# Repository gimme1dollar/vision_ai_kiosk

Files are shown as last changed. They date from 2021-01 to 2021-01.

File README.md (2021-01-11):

# Viosk
폭 넓은 사용층을 고려한 AI-기반의 **비전인식 키오스크** 
- [소개 영상](https://drive.google.com/file/d/1KaQiv4moTRgdAZZi3DC1T_f7XEgCQWQI/view?usp=sharing) 
    - 이미지 출처: `files/_image_reference.txt`
- [시연 영상](https://drive.google.com/file/d/1vzOOIthxaEInF-no1CoXh7OKscDMb2IW/view?usp=sharing)
- [발표 자료](https://drive.google.com/file/d/1hJ28Oalcn_aavSERfy1kXunzW1Yjd5MP/view?usp=sharing)

### 🎉 수상 🎉
[2021 서울 하드웨어 해커톤](https://www.seoulhackathon.org/692) 에서 우수상을 수상했습니다.

## 개요
### Goal
1. 코로나-19 시대 이후 비접촉 무인 시스템의 활성화로 인해 더 많아진 터치스크린 기반 키오스크의
2. 사용을 어려워하는 글자를 읽는 데에 어려움이 있으시는 분, 높이가 맞지 않아 터치가 힘드신 분, 휠체어를 타시는 분들을 위해
3. 비전 인식 AI를 활용해 더 나은 사용 환경을 제공하는 키오스크

### Overall Structure
<p align="center">
	
	
	
</p>

## Development
### Environment
#### STM32
- STM-B-L4S5I-IOT01A : Board
- STM32CubeMX : Development Tool
- STM32CubeAI : AI Library

#### Hardware 
- Fusion360 : 3D modeling
- Galaxy Tab : mini-screen Kiosk

#### Firmware
- Rasberry Pi : 사진 촬영 및 사진 전송 (UART)

#### Software
- Keras (ver.2.4.0) : Convolutional Neural Network for Vision Recognition
- Kotlin : Android Application Development

### Features
#### Age Detection
- [AgeGenderDeepLearning](https://github.com/GilLevi/AgeGenderDeepLearning) 모델을 base로 진행
- [IMDB-Wiki](https://data.vision.ee.ethz.ch/cvl/rrothe/imdb-wiki/) 로 학습

##### Normalize, class grouping, gray scale 변환 등의 preprocessing 진행
<p align="center">


</p>

##### Training 결과, 90%의 정확도를 보임
<p align="center">

</p>

##### Parameter 축소, quantization 등을 통해 여전히 높은 정확도를 보이는 lightweight 모델 생성 및 STM32 보드에 탑재
<p align="center">


</p>

#### UI
##### 초음파 센서를 이용해 키를 인지하고, 그에 맞춰 키오스크 높이를 조정
<p align="center">



</p>

##### Age detection 결과에 맞춰, UI를 변경
<p align="center">
    
</p>

## Contributors
<p align="center">
    
</p>

- 김현성(HW) - https://github.com/hyunsungkim
- 김주환(HW) - https://github.com/robotjuhwan  
- 이주용(SW) - https://github.com/gimme1dollar  
- 조승혁(SW) - https://github.com/seunghyukcho

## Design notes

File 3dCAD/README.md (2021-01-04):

# 3dCAD
- 3d CAD files (.stl)
- Fusion 360 (.f3d)
- Printable files of Cubicon machines (.hfb, .hvs)

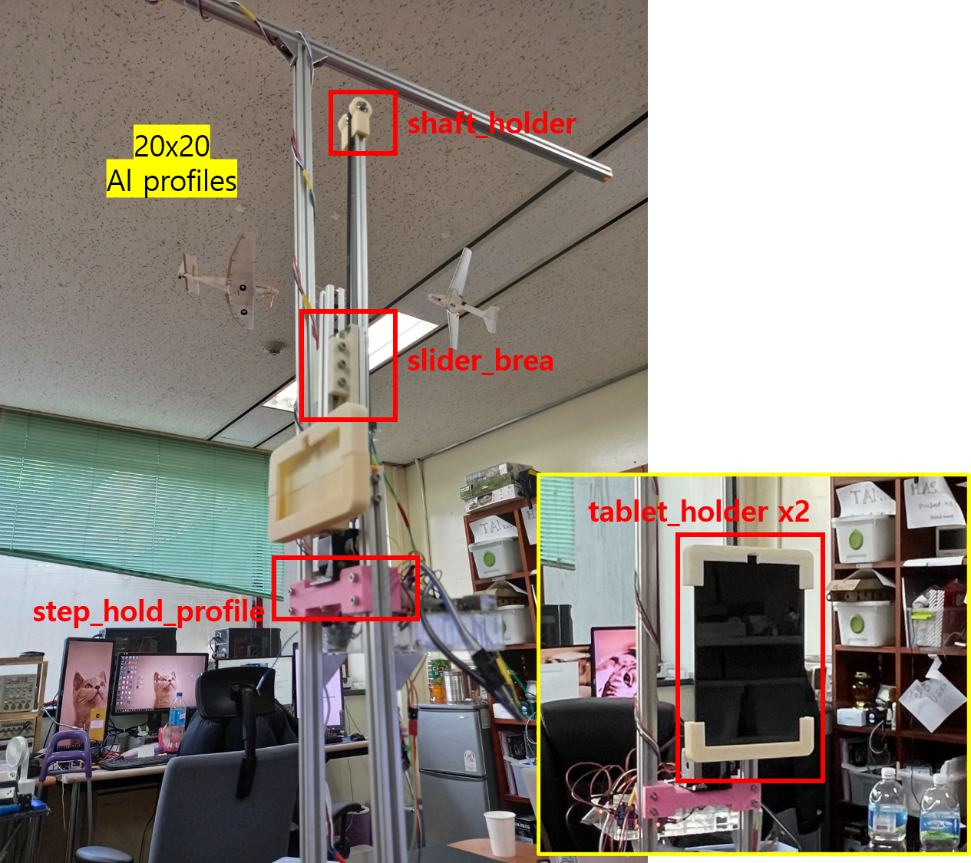
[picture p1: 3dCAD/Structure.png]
Structure


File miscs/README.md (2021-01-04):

# Miscellaneous sources

## Raspberry Pi
### Settings
1. ```sudo raspi-config```
2. Interface Options
3. Serial
4. Would you like a login shell to be accessible over serial? -> No
5. Would you like the serial port hardware to be enabled? -> Yes

### Connection to the STM board
Refer to firmware [README.md](../firmware/README.md)

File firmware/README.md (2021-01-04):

# STM32 Firmware
ST B-L4S5I-IOT01A 보드 펌웨어. 

## Environments

- ST B-L4S5I-IOT01A
- STM32CubeIDE v1.5.0
- [STM32Cube.AI][x-cube-ai-ref] v5.2.0
사용된 Tensorflow Lite model은 ai 디렉토리에 있으며, tensorflow 2.4.0 버젼에서 생성됨.

## Requirements

### Setting the STM board
Raspberry pi로부터 2Mbps의 속도로 UART 통신을 통해 이미지 데이터를 받아옴. 안정적인 통신을 위해 RTS/CTS를 통한 하드웨어 흐름제어가 필수적. RTS/CTS 흐름제어가 가능한 UART2 사용을 위해 B-L4S5I-IOT01A 보드 뒷면의 점퍼 전극을 다음과 같이 연결해야함.

SB12,16,19,20 - Close (납땜으로 연결)  
SB14,15,18,21 - Open (기존의 연결 제거)

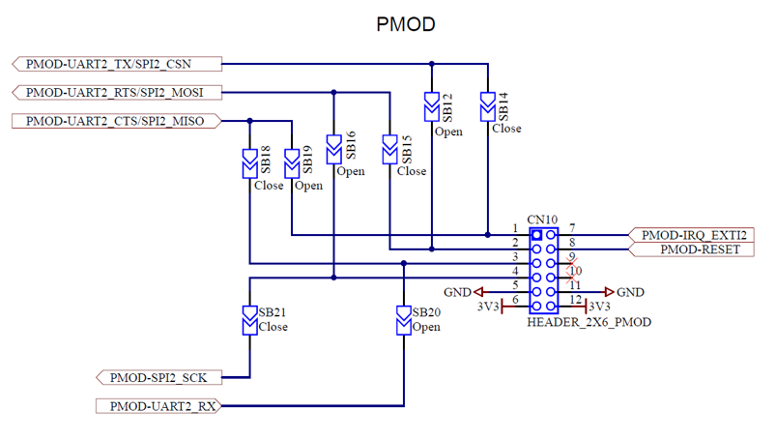
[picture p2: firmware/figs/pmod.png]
pmod


### Connections to peripherals
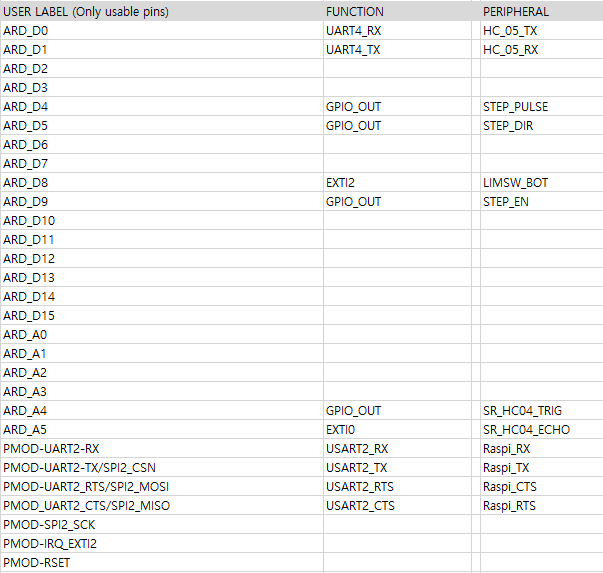
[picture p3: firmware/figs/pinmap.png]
pinmap


***SR-HC04***  
SR_HC04_TRIG : Trigger pin  
SR_HC04_ECHO : Echo pin

***MW-VSTB24D1S-v2***  
STEP_PULSE : CLK+  
STEP_DIR : DIR+  
STEP_EN : ENA+  

***HC-05***  
HC_05_TX : TX  
HC_05_RX : RX  
baud 9600bps

***Raspberry Pi 4***  
[Reference][rpi-rts-cts] 
Raspi_RX : pin 10  
Raspi_TX : pin 8  
Raspi_CTS : pin 36  
Raspi-RTS : pin 11  

## How to start

1) Raspberry Pi에서 serial.py 실행
2) STM32펌웨어 업로드 및 실행
3) 라즈베리파이 카메라에 얼굴을 비치고 SR-HC04로 사람이 감지되면 얼굴 촬영 후 나이 인식 및 키오스크 높이 조절

   [x-cube-ai-ref]: <https://www.st.com/resource/en/user_manual/dm00570145-getting-started-with-xcubeai-expansion-package-for-artificial-intelligence-ai-stmicroelectronics.pdf>
   [rpi-rts-cts]: <https://ethertubes.com/wp-content/uploads/uart_raspberry_pi_3_pinout.png>

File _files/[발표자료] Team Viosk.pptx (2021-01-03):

## Team Viosk

모두를 위한 비전인식 키오스크

## 문제점

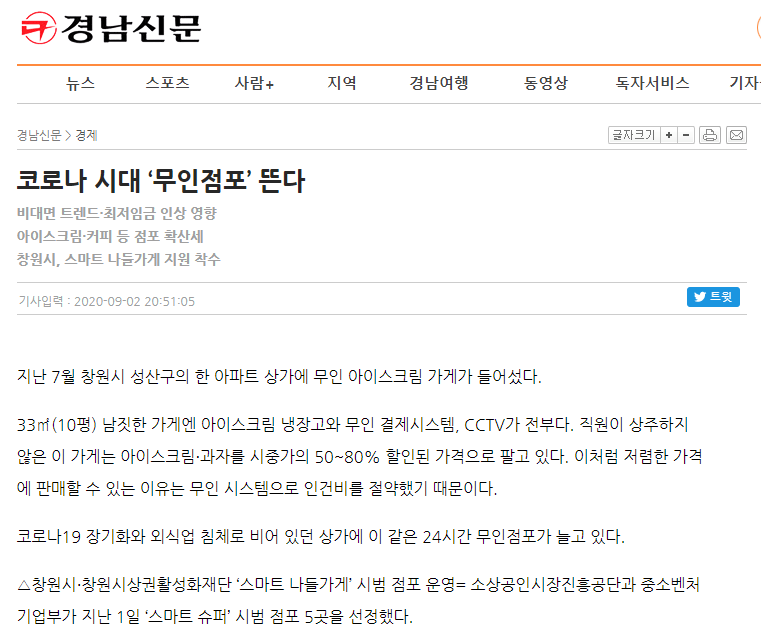
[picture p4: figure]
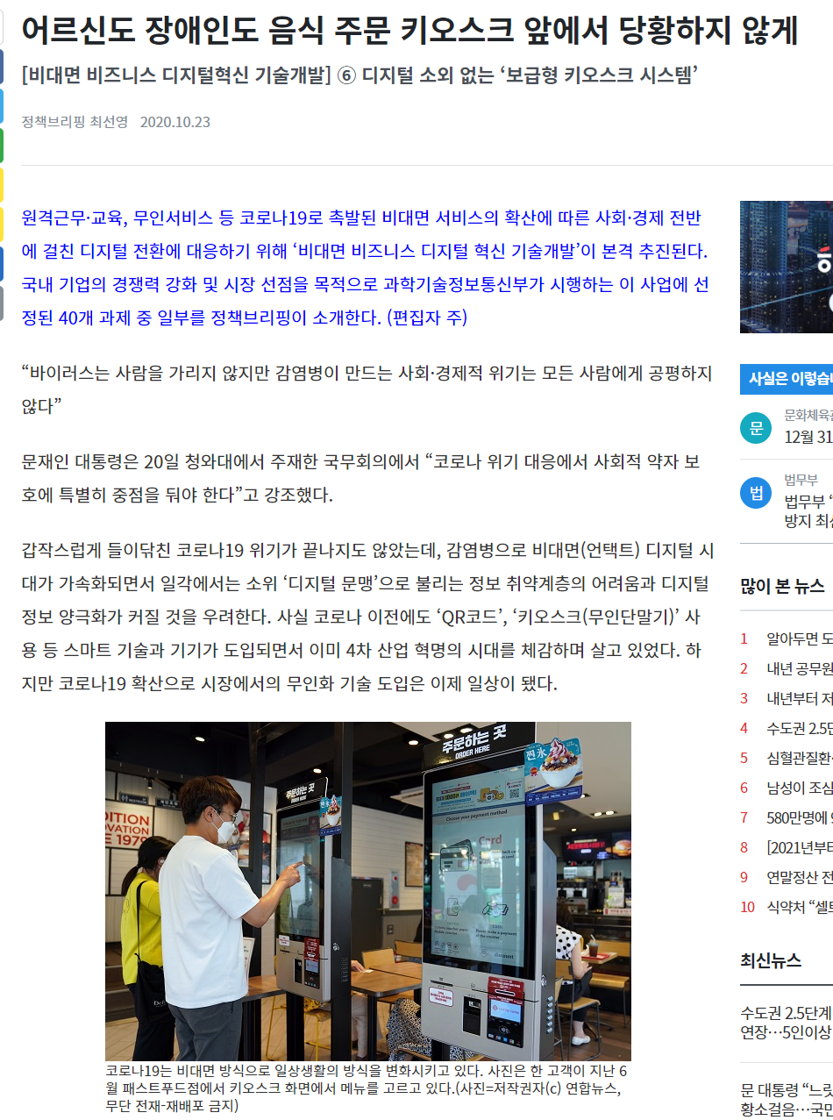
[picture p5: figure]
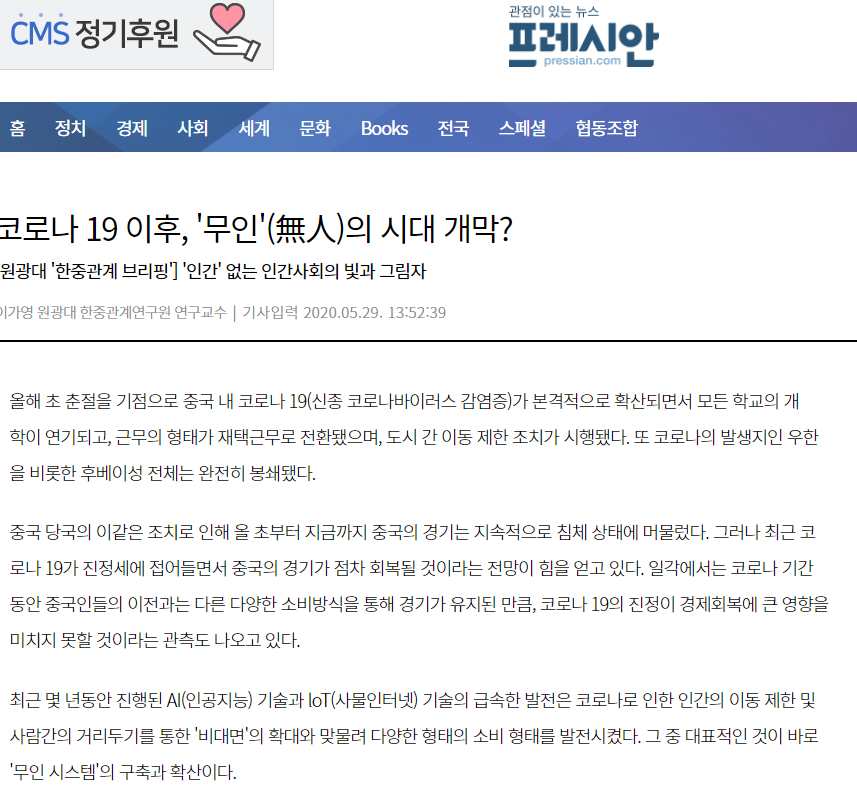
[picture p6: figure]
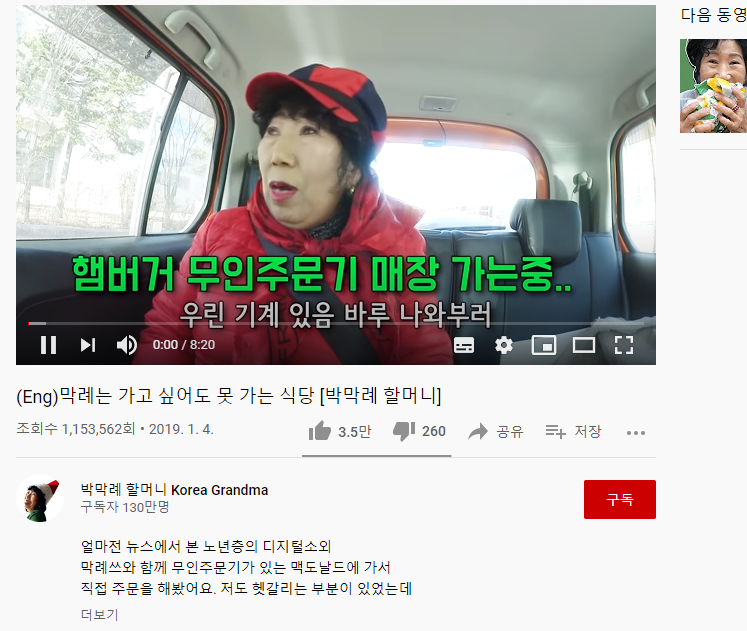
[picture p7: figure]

출처 : https://www.korea.kr/news/policyNewsView.do?newsId=148879041
https://www.pressian.com/pages/articles/2020052815135938466
http://www.knnews.co.kr/news/articleView.php?idxno=1333128
https://www.youtube.com/watch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

## 목표

- 코로나-19 시대 이후 비접촉 무인 시스템의 활성화로 인해 더 많아진 터치스크린 기반 키오스크의
- 글자를 읽는 데에 어려움이 있으시는 분, 높이가 맞지 않아 터치가 힘드신 분, 휠체어를 타시는 분들 등 사회 구성원 모두를 위해
- 비전 인식 AI를 활용해 더 나은 사용 환경을 제공하는 키오스크

## 해결책 - 자동화

- goal) AI를 이용해 사용자의 (1) 활동 DB와 (2) 의도를 읽어내어 주문 업무 완전 자동화
- 중간단계) 비전인식 및 음성인식을 활용해 사용자의 많은 정보를 추출하여 주문 업무 부분 자동화
- 현재 prototype) 비전 인식으로 사용자의 얼굴에서부터 정보 (나이 정보 등) 를 추출하고, 센서로 사용자 위치 추정을 활용해 더 나은 하드웨어/소프트웨어적인 UI 제공 자동화
- 해커톤 중점사항) 20만원 이하 수준의 리소스로 경량 AI 활용하여 10초 내외 정보 추출 및 UI 다양화 구상과 가능성 파악

## 구성

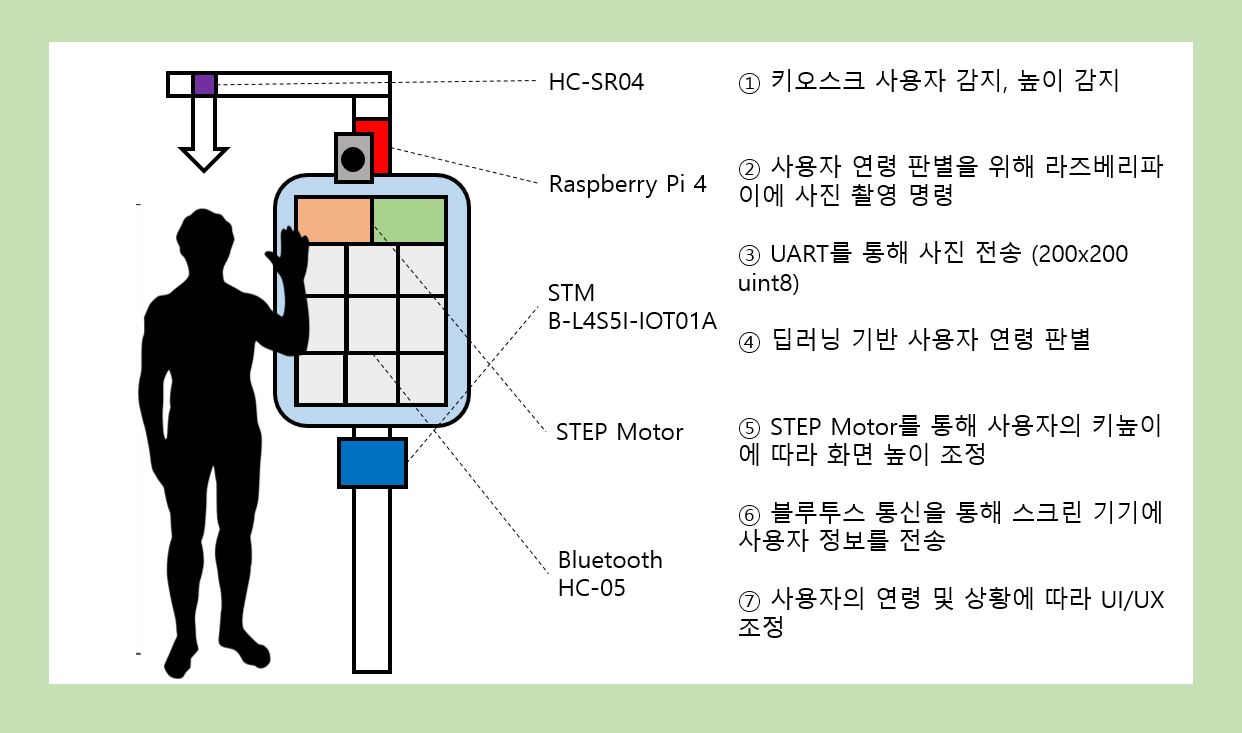
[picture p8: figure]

## 시스템

Bluetooth
HC-05

STM
B-L4S5I-IOT01A

DNN

HC-SR04

Touch Screen
UI/UX

⑥

⑥

STEP Motor

⑤

③

Raspberry Pi 4

④

②

①

⑦

## 개발 환경

STM32
- STM-B-L4S5I-IOT01A
- STM32Cube-MX : STM32 Development Tool
- STM32Cube-AI : STM32 AI 개발
Hardware
- Fusion360 : 3D modeling
- Galaxy Tab : mini-screen Kiosk
Firmware
- Rasberry Pi : 사진 촬영 및 사진 전송 (UART)
Software
- Keras (ver.2.4.0) : Convolutional Neural Network for Vision Recognition
- Kotlin : Android Application Development

## Development – 3D Modeling & 프레임

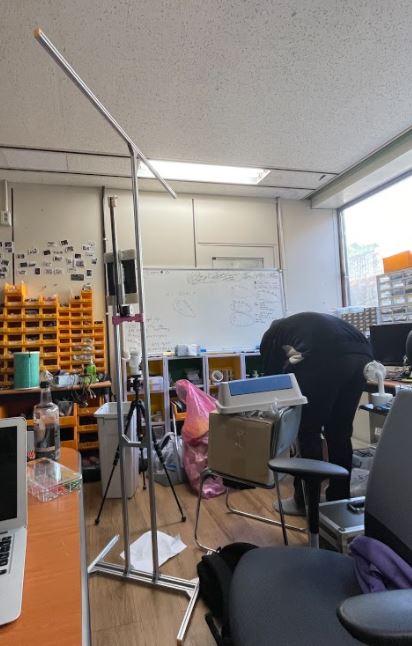
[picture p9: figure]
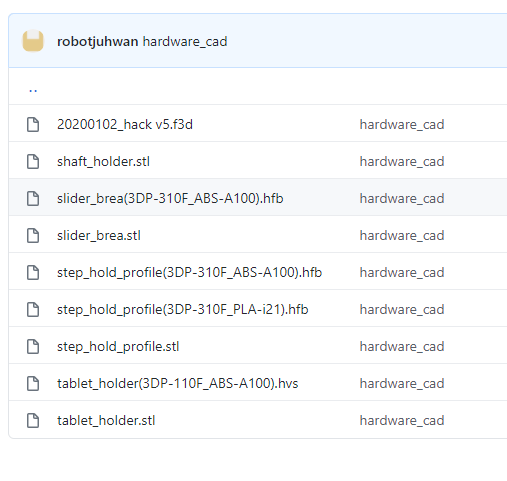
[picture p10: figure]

## Development – Image Preprocessing

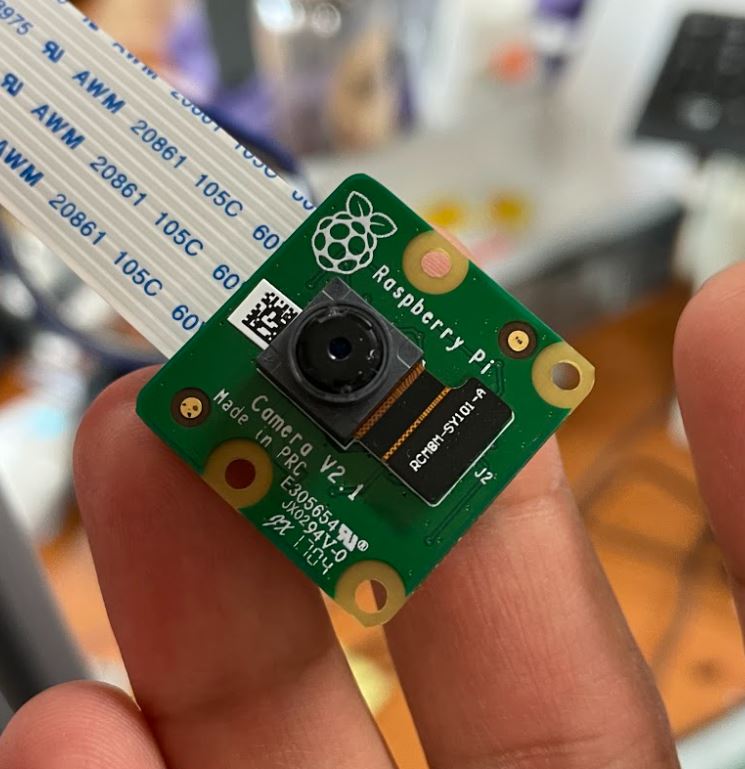
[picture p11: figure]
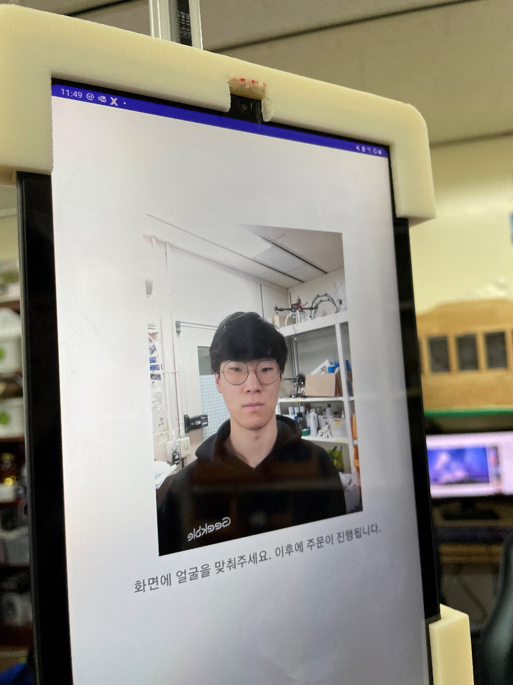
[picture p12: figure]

## Development – AI Training

- https://data.vision.ee.ethz.ch/cvl/rrothe/imdb-wiki/
- https://github.com/GilLevi/AgeGenderDeepLearning

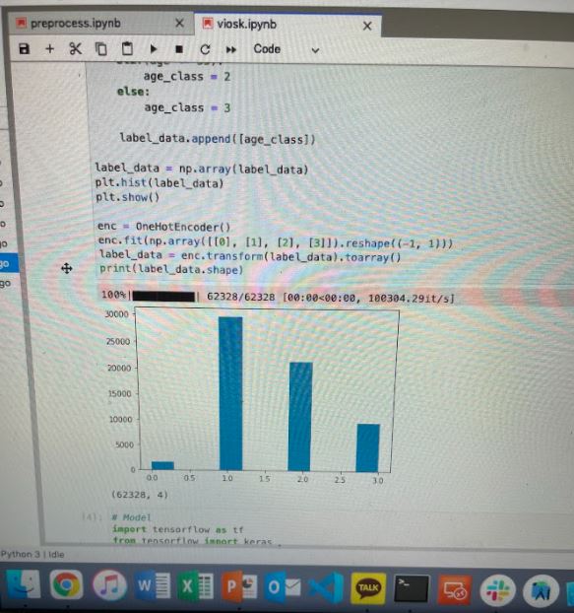
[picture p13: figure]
프리프로세싱
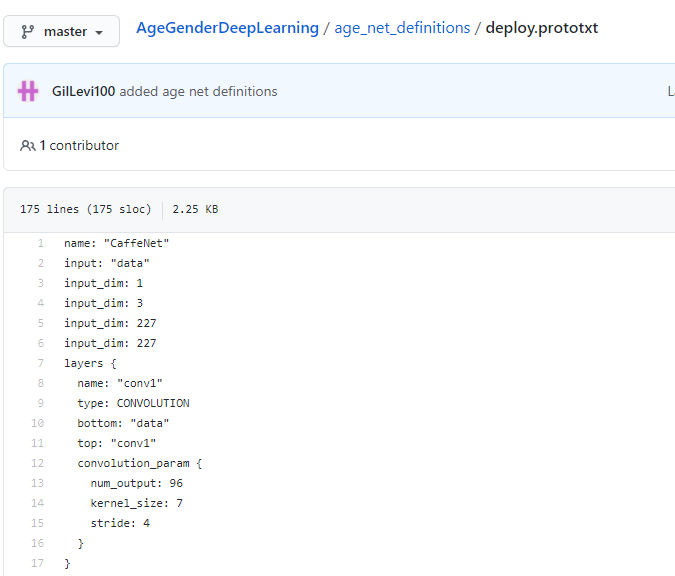
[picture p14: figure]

## Development – AI Model Quantization

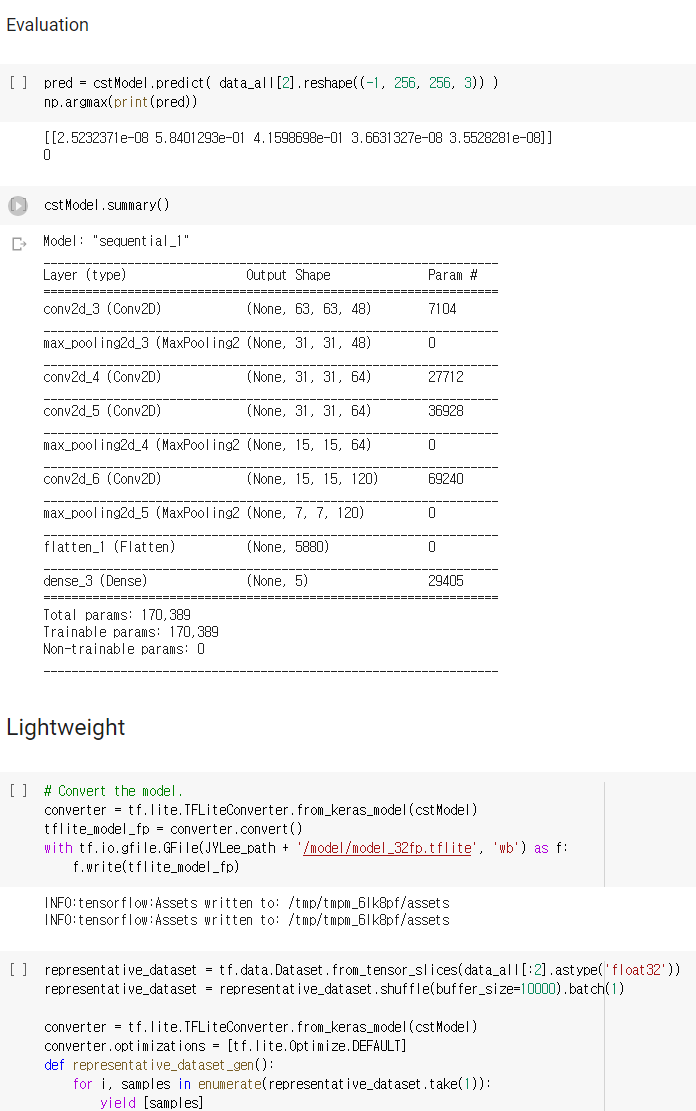
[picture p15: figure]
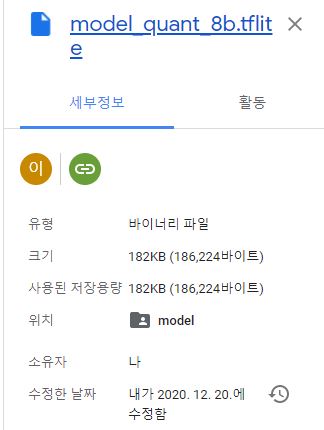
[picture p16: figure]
경량화

## Test – Age Detection

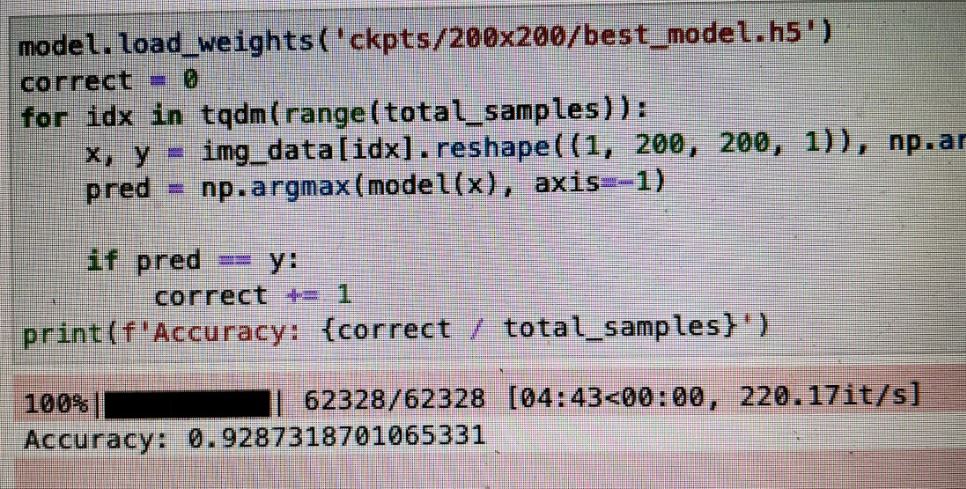
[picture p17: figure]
정확도
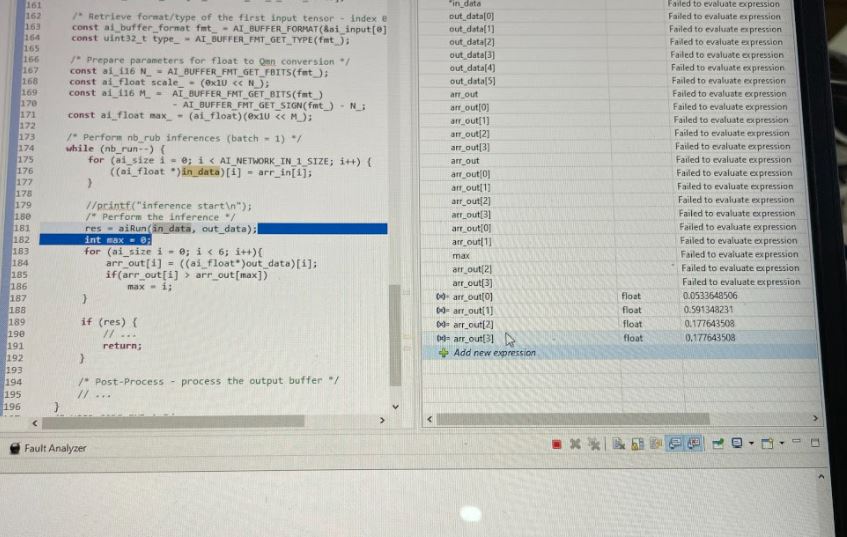
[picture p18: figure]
테스트on보드

## Test – Height Estimation

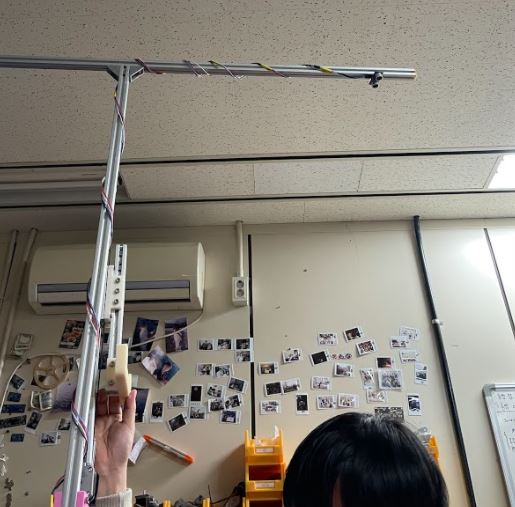
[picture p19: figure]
초음파
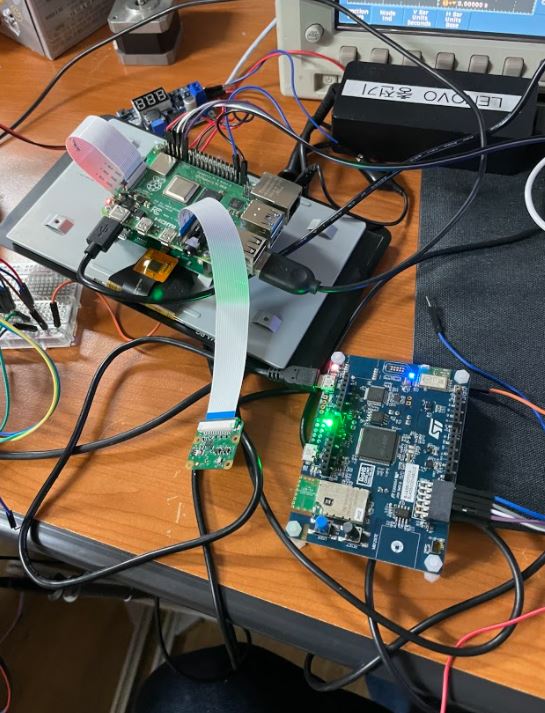
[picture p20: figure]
보드
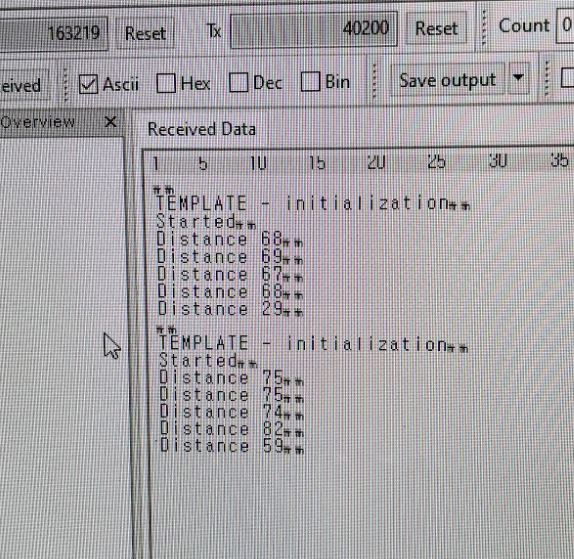
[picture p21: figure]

## Test – Hardware Adjustment

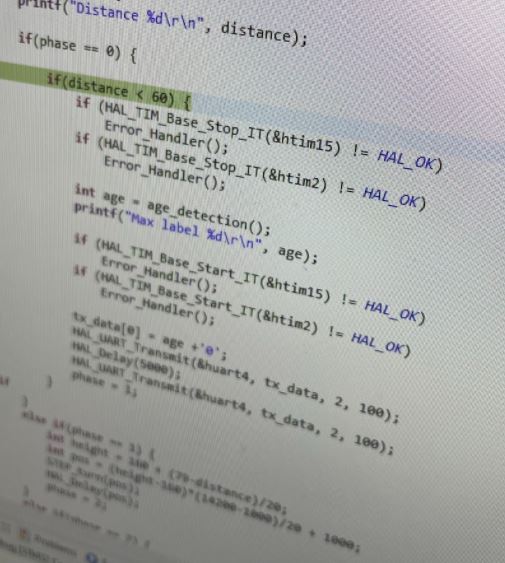
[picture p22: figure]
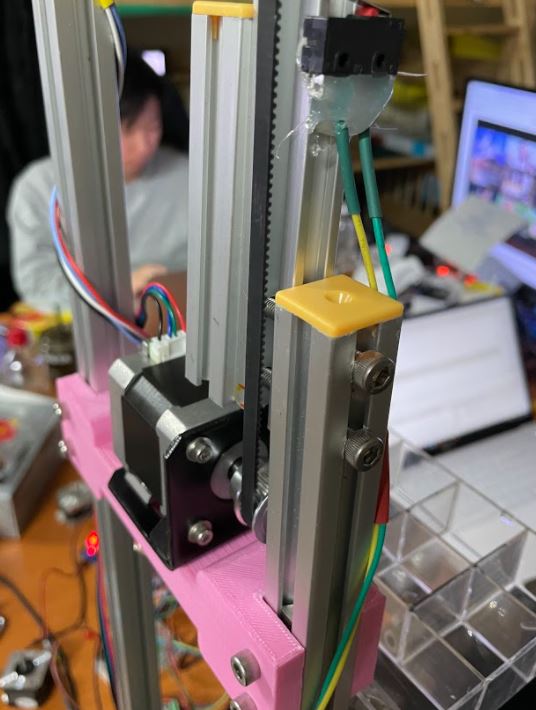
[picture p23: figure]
모터

## Test – UI Variation

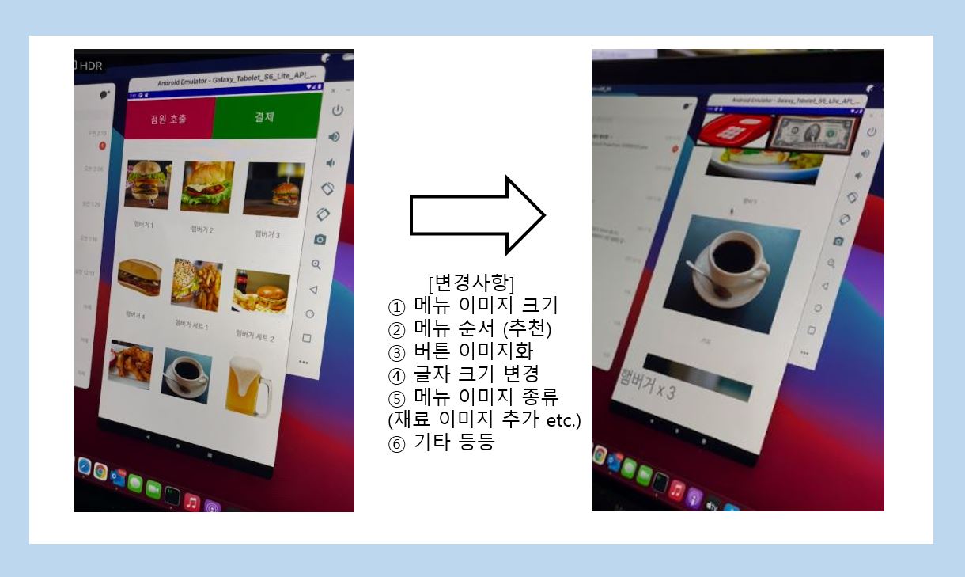
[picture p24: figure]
UI버전

## 감사합니다

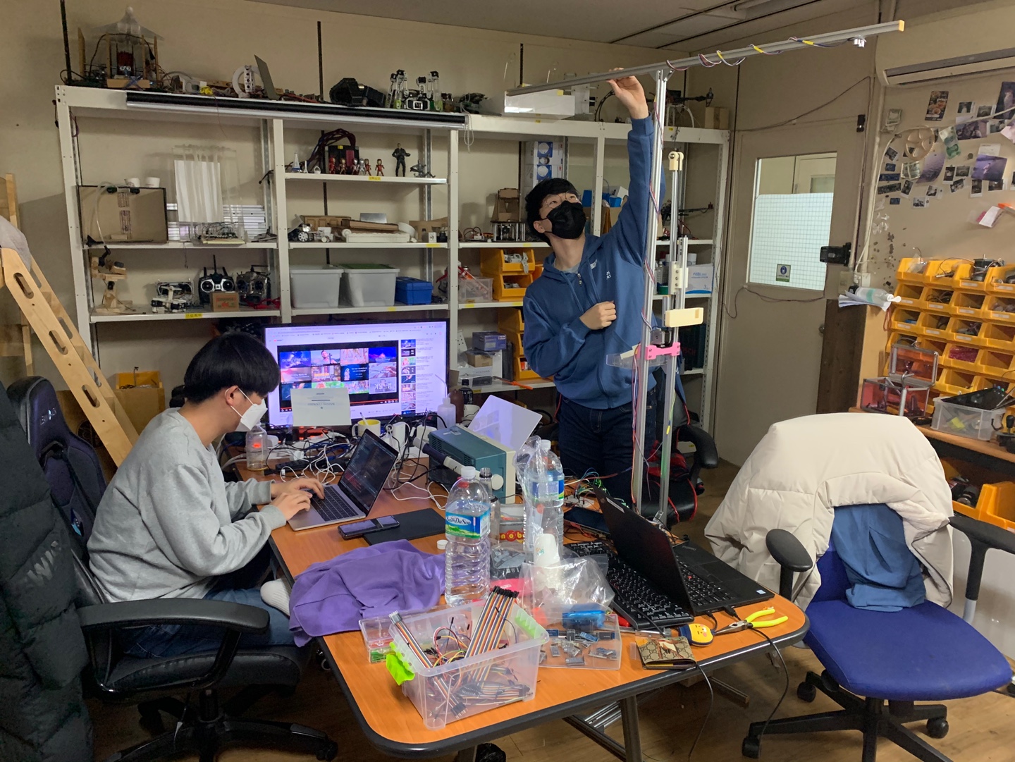
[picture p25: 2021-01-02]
작업사진/KakaoTalk_20210102_205341306.jpg

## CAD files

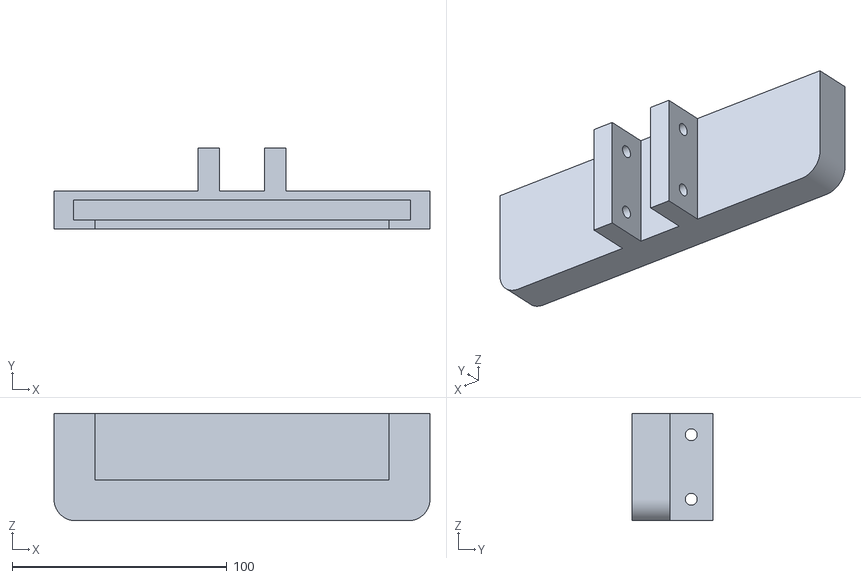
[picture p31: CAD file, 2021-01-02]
3dCAD/tablet_holder.stl
175.0 x 37.5 x 50.0

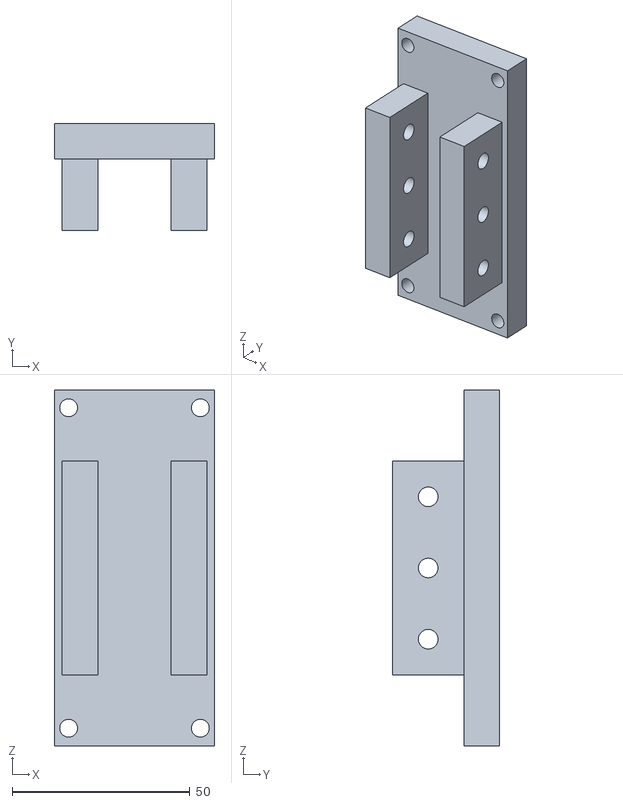
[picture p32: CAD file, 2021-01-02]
3dCAD/slider_brea.stl
45.0 x 30.0 x 100.0

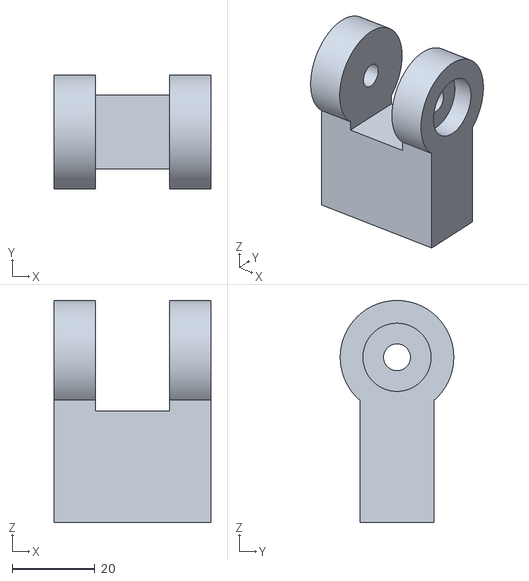
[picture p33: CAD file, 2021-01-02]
3dCAD/shaft_holder.stl
38.0 x 27.5 x 53.7

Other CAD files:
3dCAD/20200102_hack v5.f3d

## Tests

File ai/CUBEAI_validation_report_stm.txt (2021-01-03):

RUN Stats    : batches=200 dur=2257.297s tfx=2252.055s 13.878KiB/s (wb=31250.000KiB,rb=3.125KiB) 
 
Results for 200 inference(s) @120/120MHz (macc:51607476) 
 device      : 0x470/STM32L4Rxxx @120MHz/120MHz (FPU is present) lat=5 ART: ICen DCen 
 duration    : 1245.855 ms (average) 
 CPU cycles  : 149502656 (average) 
 cycles/MACC : 2.90 (average for all layers) 
 c_nodes     : 8 
 
Clayer  id  desc                          oshape          fmt       ms        (%)    
------------------------------------------------------------------------------------- 
0       0   10009/(Nonlinearity)          (200, 200, 1)   int8      7.297       0.6%   
1       1   10011/(Merged Conv2d / Pool)  (24, 24, 48)    int8      181.528    14.6%   
2       3   10004/(2D Convolutional)      (24, 24, 64)    int8      379.748    30.5%   
3       4   10011/(Merged Conv2d / Pool)  (11, 11, 64)    int8      467.198    37.5%   
4       6   10011/(Merged Conv2d / Pool)  (5, 5, 120)     int8      209.650    16.8%   
5       9   10005/(Dense)                 (1, 1, 4)       int8      0.418       0.0%   
6       9   10009/(Nonlinearity)          (1, 1, 4)       float32   0.003       0.0%   
7       10  10009/(Nonlinearity)          (1, 1, 4)       float32   0.013       0.0%   
                                                                    1245.855 (total) 
 
-- Running STM32 C-model - done (elapsed time 2257.550s) 
-- Running original model 
.......................................................................................... 
-- Running original model - done (elapsed time 47.814s) 
 
Saving data in "C:\Users\HyunsungKim\.stm32cubemx" folder 
 "network_val_m_inputs_1.csv" NOT created (SAMPLE DATA size limit exceeded: 40000 > 1024) 
 creating "network_val_m_outputs_1.csv" (only the first 64 SAMPLES are saved) dtype=[float32] 
 "network_val_c_inputs_1.csv" NOT created (SAMPLE DATA size limit exceeded: 40000 > 1024) 
 creating "network_val_c_outputs_1.csv" (only the first 64 SAMPLES are saved) dtype=[float32] 
 creating "network_val_io.npz" 
 
Accuracy report #1 for the generated stm32 C-model 
---------------------------------------------------------------------------------------------------- 
NOTE: Computed against the provided ground truth values 
 
 acc=94.00%, rmse=0.156175, mae=0.039023, l2r=0.321913 
 
 4 classes (200 samples) 
 ---------------------------- 
 C0        5    .    .    .   
 C1        .   84    1    .   
 C2        .    5   75    1   
 C3        .    3    2   24   
 
Accuracy report #1 for the reference model 
---------------------------------------------------------------------------------------------------- 
NOTE: Computed against the provided ground truth values 
 
 acc=94.00%, rmse=0.156170, mae=0.039795, l2r=0.323019 
 
 4 classes (200 samples) 
 ---------------------------- 
 C0        5    .    .    .   
 C1        .   84    1    .   
 C2        .    5   75    1   
 C3        .    3    2   24   
 
Cross accuracy report #1 (reference vs C-model) 
---------------------------------------------------------------------------------------------------- 
NOTE: the output of the reference model is used as ground truth/reference value 
 
 acc=100.00%, rmse=0.006823, mae=0.001519, l2r=0.014064 
 
 4 classes (200 samples) 
 ---------------------------- 
 C0        5    .    .    .   
 C1        .   92    .    .   
 C2        .    .   78    .   
 C3        .    .    .   25   

Evaluation report (summary) 
-------------------------------------------------------------------------------------------------- 
Mode                 acc      rmse      mae       l2r       tensor                                
-------------------------------------------------------------------------------------------------- 
stm32 C-model #1     94.00%   0.156175  0.039023  0.321913  nl_10 [ai_float, (1, 1, 4), m_id=10]  
original model #1    94.00%   0.156170  0.039795  0.323019  nl_10 [ai_float, (1, 1, 4), m_id=10]  
X-cross #1           100.00%  0.006823  0.001519  0.014064  nl_10 [ai_float, (1, 1, 4), m_id=10]  

Creating report file C:\Users\HyunsungKim\.stm32cubemx\network_validate_report.txt 
elapsed time (validate): 2306.87s 
Validation ended

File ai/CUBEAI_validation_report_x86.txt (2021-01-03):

Starting AI validation on desktop with custom dataset : C:\Users\HyunsungKim\Downloads\tflite_validation (4).npz... 
C:/Users/HyunsungKim/STM32Cube/Repository/Packs/STMicroelectronics/X-CUBE-AI/5.2.0/Utilities/windows/stm32ai validate --name network -m C:/Users/HyunsungKim/Downloads/model_200x200_quant_8b.tflite --type tflite --compression 1 --verbosity 1 --workspace C:\Users\HYUNSU~1\AppData\Local\Temp\mxAI_workspace6916350536050009154176857862252003 --output C:\Users\HyunsungKim\.stm32cubemx --valinput C:/Users/HyunsungKim/Downloads/tflite_validation (4).npz  
Neural Network Tools for STM32 v1.4.0 (AI tools v5.2.0) 
-- Importing model 
-- Importing model - done (elapsed time 0.201s) 
-- Building X86 C-model 
Creating user workspace: C:\Users\HYUNSU~1\AppData\Local\Temp\mxAI_workspace6916350536050009154176857862252003\inspector_network\workspace 
-- Building X86 C-model - done (elapsed time 0.930s) 
-- Setting inputs (and outputs) data 
Using input file(s), shapes=[(1000, 200, 200)] dtype=[float32] 
Using reference output file(s), shapes=[(1000, 4)] dtype=[int64] 
-- Setting inputs (and outputs) data - done (elapsed time 0.193s) 
-- Running X86 C-model 
........................................................................................................................................................................................................... 
-- Running X86 C-model - done (elapsed time 104.847s) 
-- Running original model 
............................................................................................................................................................................................................................................................................................................................................................................................................................................................................. 
-- Running original model - done (elapsed time 234.731s) 
 
Saving data in "C:\Users\HyunsungKim\.stm32cubemx" folder 
 "network_val_m_inputs_1.csv" NOT created (SAMPLE DATA size limit exceeded: 40000 > 1024) 
 creating "network_val_m_outputs_1.csv" (only the first 64 SAMPLES are saved) dtype=[float32] 
 "network_val_c_inputs_1.csv" NOT created (SAMPLE DATA size limit exceeded: 40000 > 1024) 
 creating "network_val_c_outputs_1.csv" (only the first 64 SAMPLES are saved) dtype=[float32] 
 creating "network_val_io.npz" 
 
Accuracy report #1 for the generated x86 C-model 
---------------------------------------------------------------------------------------------------- 
NOTE: Computed against the provided ground truth values 
 
 acc=90.20%, rmse=0.195343, mae=0.061228, l2r=0.410063 
 
 4 classes (1000 samples) 
 ---------------------------- 
 C0       19    5    .    .   
 C1        1   455   3    3   
 C2        .   54   305   3   
 C3        .   25    4   123  
 
Accuracy report #1 for the reference model 
---------------------------------------------------------------------------------------------------- 
NOTE: Computed against the provided ground truth values 
 
 acc=90.10%, rmse=0.195329, mae=0.061940, l2r=0.411457 
 
 4 classes (1000 samples) 
 ---------------------------- 
 C0       19    5    .    .   
 C1        1   455   3    3   
 C2        .   55   304   3   
 C3        .   25    4   123  
 
Cross accuracy report #1 (reference vs C-model) 
---------------------------------------------------------------------------------------------------- 
NOTE: the output of the reference model is used as ground truth/reference value 
 
 acc=99.90%, rmse=0.007288, mae=0.001633, l2r=0.015299 
 
 4 classes (1000 samples) 
 ---------------------------- 
 C0       20    .    .    .   
 C1        .   539   1    .   
 C2        .    .   311   .   
 C3        .    .    .   129  

Evaluation report (summary) 
-------------------------------------------------------------------------------------------------- 
Mode                 acc      rmse      mae       l2r       tensor                                
-------------------------------------------------------------------------------------------------- 
x86 C-model #1       90.20%   0.195343  0.061228  0.410063  nl_10 [ai_float, (1, 1, 4), m_id=10]  
original model #1    90.10%   0.195329  0.061940  0.411457  nl_10 [ai_float, (1, 1, 4), m_id=10]  
X-cross #1           99.90%   0.007288  0.001633  0.015299  nl_10 [ai_float, (1, 1, 4), m_id=10]  

Creating report file C:\Users\HyunsungKim\.stm32cubemx\network_validate_report.txt 
elapsed time (validate): 342.39s 
Validation ended

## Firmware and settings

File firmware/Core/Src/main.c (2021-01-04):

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
/* Includes ------------------------------------------------------------------*/
#include "main.h"
#include "crc.h"
#include "tim.h"
#include "usart.h"
#include "gpio.h"
#include "app_x-cube-ai.h"

/* USER CODE BEGIN PD */

// SR-HC14
#define SR_STATE_IDLE 0 // idle
#define SR_STATE_REQ 1	// user requested to measure
#define SR_STATE_TRIG 2 // triggering
#define SR_STATE_WAIT 3 // waiting echo back
#define SR_STATE_ECHO 4 // measuring echo pulse duration

// STEPPER MOTOR
#define STEP_DIRECTION_CW 0
#define STEP_DIRECTION_CCW 1
#define STEP_MODE_DISABLE 0
#define STEP_MODE_STALL 1
#define STEP_MODE_DYNAMIC 2
/* USER CODE END PD */


/* USER CODE BEGIN PV */

// AI
volatile float img[40000];
volatile uint16_t img_idx = 0;
volatile uint8_t rx_data;

// Timer instances and ticks
extern TIM_HandleTypeDef htim15;
extern TIM_HandleTypeDef htim2;
volatile uint64_t us_count = 0;

// SR-HC14
volatile uint8_t sr_state = SR_STATE_IDLE;
volatile uint64_t sr_trigger_us = 0, sr_echo_us = 0;
volatile uint32_t sr_elapsed_us;

// USART
volatile uint8_t rx_data;

// STEPPER MOTOR
volatile uint32_t step_cnt = 0;
volatile uint32_t step_target = 0;
volatile uint8_t step_mode = STEP_MODE_STALL;
volatile uint8_t step_init = 0;

/* USER CODE END PV */

void SystemClock_Config(void);
/* USER CODE BEGIN PFP */

void HAL_GPIO_EXTI_Callback(uint16_t GPIO_Pin);
void STEP_turn(uint32_t count_step);
uint16_t SR_ReadDistance(int *sr_state, unsigned long *sr_elapsed_us);
uint64_t HAL_GetTickUS();
void HAL_TIM_PeriodElapsedCallback(TIM_HandleTypeDef *htim);
void HAL_UART_RxCpltCallback(UART_HandleTypeDef *huart);
int __io_putchar(int ch);
int _write(int file, char *ptr, int len);
/* USER CODE END PFP */

/* USER CODE BEGIN 0 */
int age_detection()
{
	float aiout[4];
	int max = 0;

	HAL_UART_Transmit(&huart2, 'a', 1, 1000);
	while(img_idx<40000);

	MX_X_CUBE_AI_Process(img, aiout);

	for (int i = 0; i < 6; i++){
		if(aiout[i] > aiout[max])
			max = i;
	}
	//HAL_UART_Transmit(&huart2, img, 40000, 1000);
	img_idx = 0;
	memset(img, 0, sizeof(img));
	return max;
}
/* USER CODE END 0 */

/**
  * @brief  The application entry point.
  * @retval int
  */
int main(void)
{
  /* USER CODE BEGIN 1 */
	int16_t distance = 0;
	uint8_t tx_data[3] = {0,'\r','\n'};
	uint8_t phase = 0;
  /* USER CODE END 1 */

  /* MCU Configuration--------------------------------------------------------*/

  /* Reset of all peripherals, Initializes the Flash interface and the Systick. */
	HAL_Init();

  /* Configure the system clock */
	SystemClock_Config();

  /* Initialize all configured peripherals */
	MX_GPIO_Init();
	MX_UART4_Init();
	MX_USART1_UART_Init();
	MX_USART2_UART_Init();
	MX_USART3_UART_Init();
	MX_TIM15_Init();
	MX_TIM2_Init();
	MX_CRC_Init();
	MX_X_CUBE_AI_Init();
  /* USER CODE BEGIN 2 */

	HAL_UART_Receive_IT(&huart1, &rx_data, 1);
	HAL_UART_Receive_IT(&huart2, &rx_data, 1);
	HAL_UART_Receive_IT(&huart4, &rx_data, 1);

	if (HAL_TIM_Base_Start_IT(&htim15) != HAL_OK)
	{
		Error_Handler();
	}
	if (HAL_TIM_Base_Start_IT(&htim2) != HAL_OK)
	{
		Error_Handler();
	}

	printf("Started\r\n");
	HAL_Delay(100);
  /* USER CODE END 2 */

  /* Infinite loop */
  /* USER CODE BEGIN WHILE */
	while (1)
	{
		distance = 0;
		for(int i=0; i<3; i++) {
			uint16_t d = SR_ReadDistance(&sr_state, &sr_elapsed_us);
			distance += d;
			HAL_Delay(100);
		}
		distance /= 3;
		printf("Distance %d\r\n", distance);

		if(phase == 0) {
			if(distance < 60) {
				if (HAL_TIM_Base_Stop_IT(&htim15) != HAL_OK)
					Error_Handler();
				if (HAL_TIM_Base_Stop_IT(&htim2) != HAL_OK)
					Error_Handler();

				int age = age_detection();
				printf("Max label %d\r\n", age);

				if (HAL_TIM_Base_Start_IT(&htim15) != HAL_OK)
					Error_Handler();
				if (HAL_TIM_Base_Start_IT(&htim2) != HAL_OK)
					Error_Handler();

				tx_data[0] = age +'0';
				HAL_UART_Transmit(&huart4, tx_data, 2, 100);
				HAL_Delay(5000);
				HAL_UART_Transmit(&huart4, tx_data, 2, 100);
				phase = 1;
			}
		}
		else if(phase == 1) {
			if(distance<46.5&&distance>26.5) {
				STEP_turn((double)(46.5-distance)/26.5*14200);
            //200-distance -> 180  14200
            //200-distance -> 153.5  0
            //14200:26.5 = k:a
			}
			else {
				STEP_turn(7100);
			}
		}
		else if(phase == 2) {
			if(distance>60)
				phase = 0;
		}

		HAL_Delay(500);


#if 0
    /* USER CODE END WHILE */

  MX_X_CUBE_AI_Process();
    /* USER CODE BEGIN 3 */
#endif
	}
  /* USER CODE END 3 */
}

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
/* USER CODE BEGIN 4 */

void HAL_GPIO_EXTI_Callback(uint16_t GPIO_Pin)
{
	if (GPIO_Pin == SR_ECHO_Pin)
	{
		switch (sr_state)
		{
			case SR_STATE_WAIT:
			sr_state = SR_STATE_ECHO;
			sr_echo_us = HAL_GetTickUS();
			break;
			case SR_STATE_ECHO:
			sr_state = SR_STATE_IDLE;
			sr_elapsed_us = HAL_GetTickUS() - sr_echo_us;
			break;
		}
	}
	else if (GPIO_Pin == BUTTON_EXTI13_Pin)
	{
		if (step_mode == STEP_MODE_STALL)
			step_mode = STEP_MODE_DYNAMIC;
		else
			step_mode = STEP_MODE_STALL;

		printf("STEP_ENABLE %d, %d\r\n", step_mode, TIM2->PSC);
	}
	else if (GPIO_Pin == LIMSW_BOT_Pin)
	{
		printf("Limit switch pushed\r\n");
		step_init = 1;
		//step_mode = STEP_MODE_DISABLE;
	}
}

void STEP_turn(uint32_t count_step)
{
	step_target = count_step;
	step_mode = STEP_MODE_DYNAMIC;
}

uint16_t SR_ReadDistance(int *sr_state, unsigned long *sr_elapsed_us)
{
	uint32_t t = HAL_GetTick();
	*sr_state = SR_STATE_REQ;
	while (*sr_state != SR_STATE_IDLE)
	{
		if (*sr_elapsed_us > 38000u)
		{
			return -1;
		}
		if (HAL_GetTick() - t > 500u)
			return -2;
	}
	return *sr_elapsed_us / 58;
}

uint64_t HAL_GetTickUS()
{
	return 10u * us_count;
}

void HAL_TIM_PeriodElapsedCallback(TIM_HandleTypeDef *htim)
{

	if (htim->Instance == TIM15)
	{
		// 10 us counter
		us_count++;

		// SR Ultrasonic sensor
		switch (sr_state)
		{
			case SR_STATE_REQ:
			sr_trigger_us = HAL_GetTickUS();
			sr_state = SR_STATE_TRIG;
			HAL_GPIO_WritePin(SR_TRIG_Port, SR_TRIG_Pin, GPIO_PIN_SET);
			break;
			case SR_STATE_TRIG:
			if (HAL_GetTickUS() - sr_trigger_us >= 10)
			{
				sr_state = SR_STATE_WAIT;
				HAL_GPIO_WritePin(SR_TRIG_Port, SR_TRIG_Pin, GPIO_PIN_RESET);
			}
			break;
		}

		// Blink LED2 every seconds
		if (HAL_GetTickUS() % 1000000u == 0)
		{
			HAL_GPIO_TogglePin(LED2_GPIO_Port, LED2_Pin);
		}
	}
	else if (htim->Instance == TIM2)
	{
		if (step_init == 0)
		{
			HAL_GPIO_WritePin(STEP_DIR_Port, STEP_DIR_Pin, GPIO_PIN_SET);
			HAL_GPIO_WritePin(STEP_EN_Port, STEP_EN_Pin, GPIO_PIN_RESET);
			HAL_GPIO_TogglePin(STEP_PULSE_Port, STEP_PULSE_Pin);
		}
		else
		{
			switch (step_mode)
			{
				case STEP_MODE_DISABLE:
				HAL_GPIO_WritePin(STEP_EN_Port, STEP_EN_Pin, GPIO_PIN_SET);
				break;
				case STEP_MODE_STALL:
				HAL_GPIO_WritePin(STEP_EN_Port, STEP_EN_Pin, GPIO_PIN_RESET);
				break;
				case STEP_MODE_DYNAMIC:
				HAL_GPIO_WritePin(STEP_EN_Port, STEP_EN_Pin, GPIO_PIN_RESET);
				if (step_cnt < step_target)
				{
					step_cnt++;
					HAL_GPIO_WritePin(STEP_DIR_Port, STEP_DIR_Pin, GPIO_PIN_RESET);
					HAL_GPIO_TogglePin(STEP_PULSE_Port, STEP_PULSE_Pin);
				}
				else if(step_cnt > step_target)
				{
					step_cnt--;
					HAL_GPIO_WritePin(STEP_DIR_Port, STEP_DIR_Pin, GPIO_PIN_SET);
					HAL_GPIO_TogglePin(STEP_PULSE_Port, STEP_PULSE_Pin);
				}
				else
				{
					step_mode = STEP_MODE_STALL;
				}

				break;
			}
		}
	}
}

void HAL_UART_RxCpltCallback(UART_HandleTypeDef *huart)
{
	if (huart->Instance == USART1)
	{
		HAL_UART_Receive_IT(&huart1, &rx_data, 1);
		HAL_UART_Transmit(&huart1, &rx_data, 1, 100);
	}
	if(huart->Instance == USART2) {
		HAL_UART_Receive_IT(&huart2, &rx_data, 1);
//		HAL_UART_Transmit(&huart2, &rx_data, 1, 1);
		if(img_idx<40000)
			img[img_idx++] = rx_data;
		else
			HAL_UART_Transmit(&huart2, &rx_data, 1, 1);

	}
	if (huart->Instance == UART4)
	{
		HAL_UART_Receive_IT(&huart4, &rx_data, 1);
		HAL_UART_Transmit(&huart4, &rx_data, 1, 100);
	}
}

int __io_putchar(int ch)
{
	while (HAL_OK != HAL_UART_Transmit(&huart1, (uint8_t *)&ch, 1, 3000))
		;
	return ch;
}

int _write(int file, char *ptr, int len)
{
	int DataIdx;

	for (DataIdx = 0; DataIdx < len; DataIdx++)
	{
		__io_putchar(*ptr++);
	}
	return len;
}

/* USER CODE END 4 */
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


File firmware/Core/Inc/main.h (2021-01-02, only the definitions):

#define ST25DV04K_RF_DISABLE_Pin GPIO_PIN_2
#define ST25DV04K_RF_DISABLE_GPIO_Port GPIOE
#define USB_OTG_FS_OVRCR_EXTI3_Pin GPIO_PIN_3
#define USB_OTG_FS_OVRCR_EXTI3_GPIO_Port GPIOE
#define ST25DV04K_GPO_Pin GPIO_PIN_4
#define ST25DV04K_GPO_GPIO_Port GPIOE
#define SPSGRF_915_GPIO3_EXTI5_Pin GPIO_PIN_5
#define SPSGRF_915_GPIO3_EXTI5_GPIO_Port GPIOE
#define SPBTLE_RF_IRQ_EXTI6_Pin GPIO_PIN_6
#define SPBTLE_RF_IRQ_EXTI6_GPIO_Port GPIOE
#define BUTTON_EXTI13_Pin GPIO_PIN_13
#define BUTTON_EXTI13_GPIO_Port GPIOC
#define BUTTON_EXTI13_EXTI_IRQn EXTI15_10_IRQn
#define ARD_A5_Pin GPIO_PIN_0
#define ARD_A5_GPIO_Port GPIOC
#define ARD_A5_EXTI_IRQn EXTI0_IRQn
#define ARD_A4_Pin GPIO_PIN_1
#define ARD_A4_GPIO_Port GPIOC
#define ARD_A3_Pin GPIO_PIN_2
#define ARD_A3_GPIO_Port GPIOC
#define ARD_A2_Pin GPIO_PIN_3
#define ARD_A2_GPIO_Port GPIOC
#define ARD_D1_Pin GPIO_PIN_0
#define ARD_D1_GPIO_Port GPIOA
#define ARD_D0_Pin GPIO_PIN_1
#define ARD_D0_GPIO_Port GPIOA
#define ARD_D10_Pin GPIO_PIN_2
#define ARD_D10_GPIO_Port GPIOA
#define ARD_D4_Pin GPIO_PIN_3
#define ARD_D4_GPIO_Port GPIOA
#define ARD_D7_Pin GPIO_PIN_4
#define ARD_D7_GPIO_Port GPIOA
#define ARD_D13_Pin GPIO_PIN_5
#define ARD_D13_GPIO_Port GPIOA
#define ARD_D12_Pin GPIO_PIN_6
#define ARD_D12_GPIO_Port GPIOA
#define ARD_D11_Pin GPIO_PIN_7
#define ARD_D11_GPIO_Port GPIOA
#define ARD_A1_Pin GPIO_PIN_4
#define ARD_A1_GPIO_Port GPIOC
#define ARD_A0_Pin GPIO_PIN_5
#define ARD_A0_GPIO_Port GPIOC
#define ARD_D6_Pin GPIO_PIN_1
#define ARD_D6_GPIO_Port GPIOB
#define ARD_D8_Pin GPIO_PIN_2
#define ARD_D8_GPIO_Port GPIOB
#define ARD_D8_EXTI_IRQn EXTI2_IRQn
#define DFSDM1_DATIN2_Pin GPIO_PIN_7
#define DFSDM1_DATIN2_GPIO_Port GPIOE
#define ISM43362_RST_Pin GPIO_PIN_8
#define ISM43362_RST_GPIO_Port GPIOE
#define DFSDM1_CKOUT_Pin GPIO_PIN_9
#define DFSDM1_CKOUT_GPIO_Port GPIOE
#define QUADSPI_CLK_Pin GPIO_PIN_10
#define QUADSPI_CLK_GPIO_Port GPIOE
#define QUADSPI_NCS_Pin GPIO_PIN_11
#define QUADSPI_NCS_GPIO_Port GPIOE
#define OQUADSPI_BK1_IO0_Pin GPIO_PIN_12
#define OQUADSPI_BK1_IO0_GPIO_Port GPIOE
#define QUADSPI_BK1_IO1_Pin GPIO_PIN_13
#define QUADSPI_BK1_IO1_GPIO_Port GPIOE
#define QUAD_SPI_BK1_IO2_Pin GPIO_PIN_14
#define QUAD_SPI_BK1_IO2_GPIO_Port GPIOE
#define QUAD_SPI_BK1_IO3_Pin GPIO_PIN_15
#define QUAD_SPI_BK1_IO3_GPIO_Port GPIOE
#define INTERNAL_I2C2_SCL_Pin GPIO_PIN_10
#define INTERNAL_I2C2_SCL_GPIO_Port GPIOB
#define INTERNAL_I2C2_SDA_Pin GPIO_PIN_11
#define INTERNAL_I2C2_SDA_GPIO_Port GPIOB
#define ISM43362_BOOT0_Pin GPIO_PIN_12
#define ISM43362_BOOT0_GPIO_Port GPIOB
#define ISM43362_WAKEUP_Pin GPIO_PIN_13
#define ISM43362_WAKEUP_GPIO_Port GPIOB
#define LED2_Pin GPIO_PIN_14
#define LED2_GPIO_Port GPIOB
#define SPSGRF_915_SDN_Pin GPIO_PIN_15
#define SPSGRF_915_SDN_GPIO_Port GPIOB
#define INTERNAL_UART3_TX_Pin GPIO_PIN_8
#define INTERNAL_UART3_TX_GPIO_Port GPIOD
#define INTERNAL_UART3_RX_Pin GPIO_PIN_9
#define INTERNAL_UART3_RX_GPIO_Port GPIOD
#define LPS22HB_INT_DRDY_EXTI10_Pin GPIO_PIN_10
#define LPS22HB_INT_DRDY_EXTI10_GPIO_Port GPIOD
#define LPS22HB_INT_DRDY_EXTI10_EXTI_IRQn EXTI15_10_IRQn
#define LSM6DSL_INT1_EXTI11_Pin GPIO_PIN_11
#define LSM6DSL_INT1_EXTI11_GPIO_Port GPIOD
#define LSM6DSL_INT1_EXTI11_EXTI_IRQn EXTI15_10_IRQn
#define USB_OTG_FS_PWR_EN_Pin GPIO_PIN_12
#define USB_OTG_FS_PWR_EN_GPIO_Port GPIOD
#define USB_OTG_FS_PWR_EN_EXTI_IRQn EXTI15_10_IRQn
#define SPBTLE_RF_SPI3_CSN_Pin GPIO_PIN_13
#define SPBTLE_RF_SPI3_CSN_GPIO_Port GPIOD
#define ARD_D2_Pin GPIO_PIN_14
#define ARD_D2_GPIO_Port GPIOD
#define ARD_D2_EXTI_IRQn EXTI15_10_IRQn
#define HTS221_DRDY_EXTI15_Pin GPIO_PIN_15
#define HTS221_DRDY_EXTI15_GPIO_Port GPIOD
#define HTS221_DRDY_EXTI15_EXTI_IRQn EXTI15_10_IRQn
#define VL53L0X_XSHUT_Pin GPIO_PIN_6
#define VL53L0X_XSHUT_GPIO_Port GPIOC
#define VL53L0X_GPIO1_EXTI7_Pin GPIO_PIN_7
#define VL53L0X_GPIO1_EXTI7_GPIO_Port GPIOC
#define LSM3MDL_DRDY_EXTI8_Pin GPIO_PIN_8
#define LSM3MDL_DRDY_EXTI8_GPIO_Port GPIOC
#define LED3_WIFI__LED4_BLE_Pin GPIO_PIN_9
#define LED3_WIFI__LED4_BLE_GPIO_Port GPIOC
#define SPBTLE_RF_RST_Pin GPIO_PIN_8
#define SPBTLE_RF_RST_GPIO_Port GPIOA
#define USB_OTG_FS_VBUS_Pin GPIO_PIN_9
#define USB_OTG_FS_VBUS_GPIO_Port GPIOA
#define SYS_JTMS_SWDIO_Pin GPIO_PIN_13
#define SYS_JTMS_SWDIO_GPIO_Port GPIOA
#define SYS_JTCK_SWCLK_Pin GPIO_PIN_14
#define SYS_JTCK_SWCLK_GPIO_Port GPIOA
#define ARD_D9_Pin GPIO_PIN_15
#define ARD_D9_GPIO_Port GPIOA
#define INTERNAL_SPI3_SCK_Pin GPIO_PIN_10
#define INTERNAL_SPI3_SCK_GPIO_Port GPIOC
#define INTERNAL_SPI3_MISO_Pin GPIO_PIN_11
#define INTERNAL_SPI3_MISO_GPIO_Port GPIOC
#define INTERNAL_SPI3_MOSI_Pin GPIO_PIN_12
#define INTERNAL_SPI3_MOSI_GPIO_Port GPIOC
#define PMOD_RESET_Pin GPIO_PIN_0
#define PMOD_RESET_GPIO_Port GPIOD
#define PMOD_SPI2_SCK_Pin GPIO_PIN_1
#define PMOD_SPI2_SCK_GPIO_Port GPIOD
#define PMOD_UART2_CTS_Pin GPIO_PIN_3
#define PMOD_UART2_CTS_GPIO_Port GPIOD
#define PMOD_UART2_RTS_Pin GPIO_PIN_4
#define PMOD_UART2_RTS_GPIO_Port GPIOD
#define PMOD_UART2_TX_Pin GPIO_PIN_5
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

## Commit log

2021-01-02 Implement 10 us Tick using timer 15 and printf function using USART1 connetected to ST-Link
2021-01-02 Add distance measuring function using SR-HC14 ultirasonic sensor
2021-01-02 Implement stepper motor control functions
2021-01-02 Add STEP_stall function for the stepper motor to keep torque during the stall mode
    [main.c]
2021-01-02 Add limit switch functions
2021-01-02 kiosk 구현 업로드
2021-01-02 Add RaspberryPi source code
2021-01-02 Fix ultrasonic sensor
2021-01-03 Add tensorflow lite model and related validation materials
2021-01-03 cleaned folders and readme
    [20200102_hack v5.f3d, shaft_holder.stl, slider_brea.stl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]

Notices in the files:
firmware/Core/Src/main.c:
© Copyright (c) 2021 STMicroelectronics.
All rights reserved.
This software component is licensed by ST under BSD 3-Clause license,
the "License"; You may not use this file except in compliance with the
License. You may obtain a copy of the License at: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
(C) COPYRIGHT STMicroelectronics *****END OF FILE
